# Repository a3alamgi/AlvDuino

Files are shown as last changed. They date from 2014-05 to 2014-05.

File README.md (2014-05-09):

AlvDuino
========	
After breaking an Arduino Uno I decided to build one instead of buying one. Using CadSoft EAGLE I designed a PCB layout for a custom Arduino Uno R3 board which I named the AlvDuino. I read through the Uno schematic to understand the basic hardware and overall design. I removed USB functionality and used a simpler design that can be programmed through an external programmer (USBTinyISP).  

Arduino Uno design and information can be found here: http://arduino.cc/en/Main/ArduinoBoardUno   

Here is an image of the AlvDuino:  
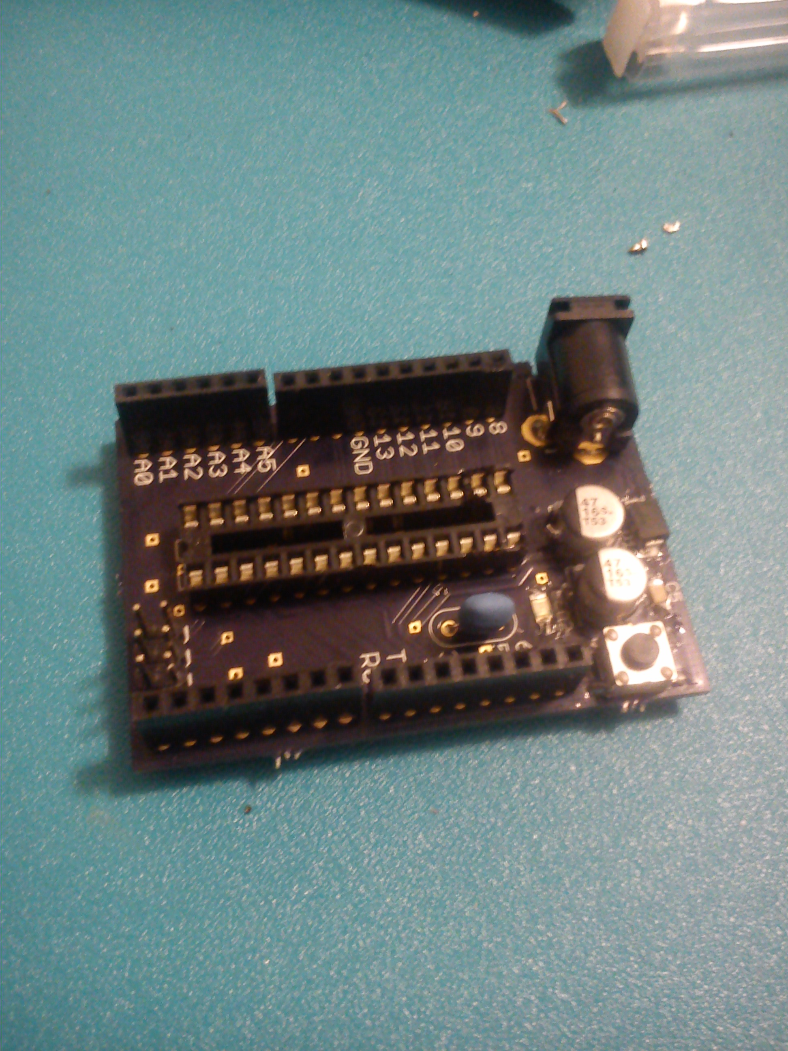
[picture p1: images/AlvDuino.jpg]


Click here to see AlvDuino in use:  
<a href="https://youtu.be/0XYK6YoSBJY">https://youtu.be/0XYK6YoSBJY</a>

Materials:
---------
Researched into use of components in the schematic and selected appropriate packages for soldering and minimizing board space
-	x3, 0.1uF ceramic capacitor, package 1206
-	x2, 47uF aluminum capacitor, SMD
-	x1, 10kΩ resistor, package 1206
-	x2, 1kΩ resistor, package 1206
-	x1, 1MΩ resistor, package 1206
-	x1, green LED, SMD
-	x2, diode, package DO214AA 
-	x1, tactile switch
-	x1, 2x3 vertical pin header 
-	x1, 1x6 female connector header
-	x2, 1x8 female connector header
-	x1, 1x10 female connector header
-	x1, 2.1mm power connector jack
-	x1, 28 position IC socket 
-	x1, 5V regulator, package SOT223, [NCP1117ST50T3G](http://www.onsemi.com/pub_link/Collateral/NCP1117-D.PDF)
-	x1, ceramic 16MHz resonator, radial-3 lead, [CSTL16M0X53-A0](http://search.murata.co.jp/Ceramy/image/img/w_hinm/L0430E.pdf)
-	x1, ATMEGA328-P DIP chip, [ATMEGA328P-PU](http://www.atmel.com/Images/doc8161.pdf)
-	Soldering assembly (solder, iron, braid, etc.)  

Design & Assembly:
-----------------
-	Designed a PCB layout for an Arduino Uno board with Atmega328P to minimize size while retaining functionality (see Figure 1)
-	Rearranged output pin positions for easier board routing
-	Positioned all pins with 0.1” pitch (or a multiple of) so that any prototype board can be used as a custom shield
-	Ordered components from DigiKey/Newark and PCB from OSHPark
-	Soldered and assembled all the components to the board
-	Used ICSP headers used to upload program through an external programmer (USBTinyISP)

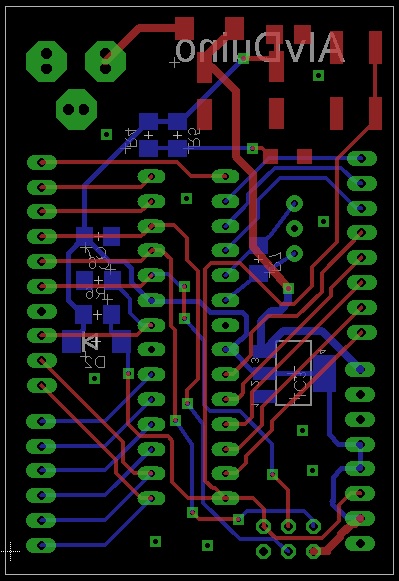
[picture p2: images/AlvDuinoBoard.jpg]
  
Figure 1: AlvDuino PCB layout

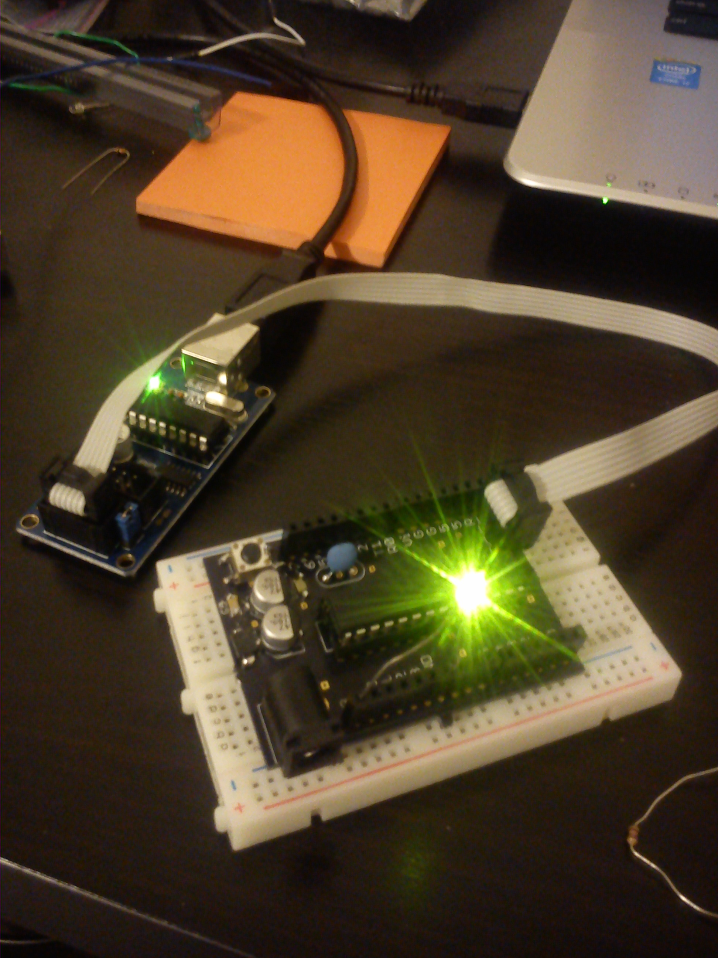
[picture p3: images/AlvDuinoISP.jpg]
  
Figure 2: Completed AlvDuino Board and USBTinyISP

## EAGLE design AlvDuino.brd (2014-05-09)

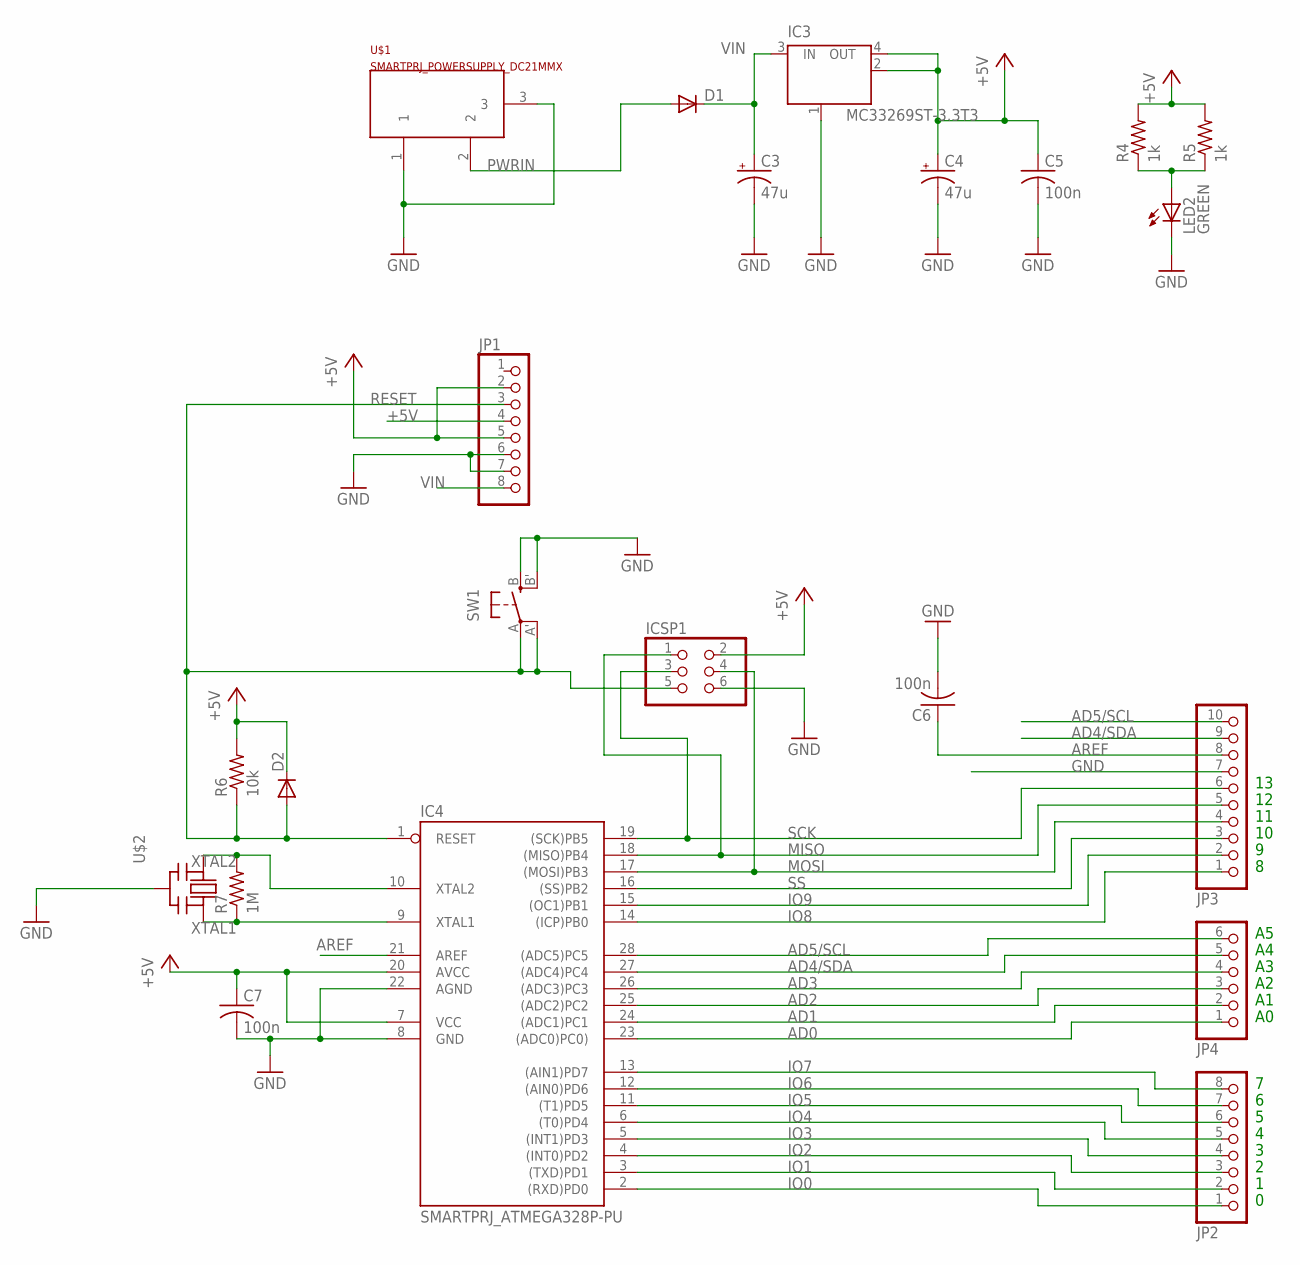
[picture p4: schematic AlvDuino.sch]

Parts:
C3, C4: 47u; PANASONIC_D
C5, C6, C7: 100n; C1206
D1, D2: DIODE-DO214AA; DO214AA
IC3: MC33269ST-3.3T3; SOT223
IC4: SMARTPRJ_ATMEGA328P-PU; SMARTPRJ_DIL28-3
ICSP1: PINHD-2X3; 2X03
JP1, JP2: PINHD-1X8; 1X08
JP3: PINHD-1X10; 1X10
JP4: PINHD-1X6; 1X06
LED2: GREEN; CHIPLED_1206
R4, R5: 1k; R1206
R6: 10k; R1206
R7: 1M; R1206
SW1: SPST_TACT-EVQQ2; EVQ-Q2
U$1: SMARTPRJ_POWERSUPPLY_DC21MMX; SMARTPRJ_POWERSUPPLY_DC-21MM
U$2: CERMOSCILL-THM; CERM_OSC

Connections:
+5V: C4.+, C5.1, C7.1, D2.C, IC3.2 (OUT), IC3.4 (OUT), IC4.7 (VCC), IC4.20 (AVCC), ICSP1.2, JP1.2, JP1.4, JP1.5, R4.2, R5.2, R6.2
AD0: IC4.23 ((ADC0)PC0)), JP4.1
AD1: IC4.24 ((ADC1)PC1), JP4.2
AD2: IC4.25 ((ADC2)PC2), JP4.3
AD3: IC4.26 ((ADC3)PC3), JP4.4
AD4/SDA: IC4.27 ((ADC4)PC4), JP3.9, JP4.5
AD5/SCL: IC4.28 ((ADC5)PC5), JP3.10, JP4.6
AREF: C6.1, IC4.21 (AREF), JP3.8
GND: C3.-, C4.-, C5.2, C6.2, C7.2, IC3.1 (GND/ADJ), IC4.8 (GND), IC4.22 (AGND), ICSP1.6, JP1.6, JP1.7, JP3.7, LED2.C, SW1.B (S), SW1.B' (S1), U$1.1, U$1.3, U$2.P$2 (GND)
IO0: IC4.2 ((RXD)PD0), JP2.1
IO1: IC4.3 ((TXD)PD1), JP2.2
IO2: IC4.4 ((INT0)PD2), JP2.3
IO3: IC4.5 ((INT1)PD3), JP2.4
IO4: IC4.6 ((T0)PD4), JP2.5
IO5: IC4.11 ((T1)PD5), JP2.6
IO6: IC4.12 ((AIN0)PD6), JP2.7
IO7: IC4.13 ((AIN1)PD7), JP2.8
IO8: IC4.14 ((ICP)PB0), JP3.1
IO9: IC4.15 ((OC1)PB1), JP3.2
MISO: IC4.18 ((MISO)PB4), ICSP1.1, JP3.5
MOSI: IC4.17 ((MOSI)PB3), ICSP1.4, JP3.4
unnamed: LED2.A, R4.1, R5.1
PWRIN: D1.A, U$1.2
RESET: D2.A, IC4.1 (RESET), ICSP1.5, JP1.3, R6.1, SW1.A, SW1.A' (P1)
SCK: IC4.19 ((SCK)PB5), ICSP1.3, JP3.6
SS: IC4.16 ((SS)PB2), JP3.3
VIN: C3.+, D1.C, IC3.3 (IN), JP1.8
XTAL1: IC4.9 (XTAL1), R7.1, U$2.P$3 (OUT)
XTAL2: IC4.10 (XTAL2), R7.2, U$2.P$1 (IN)

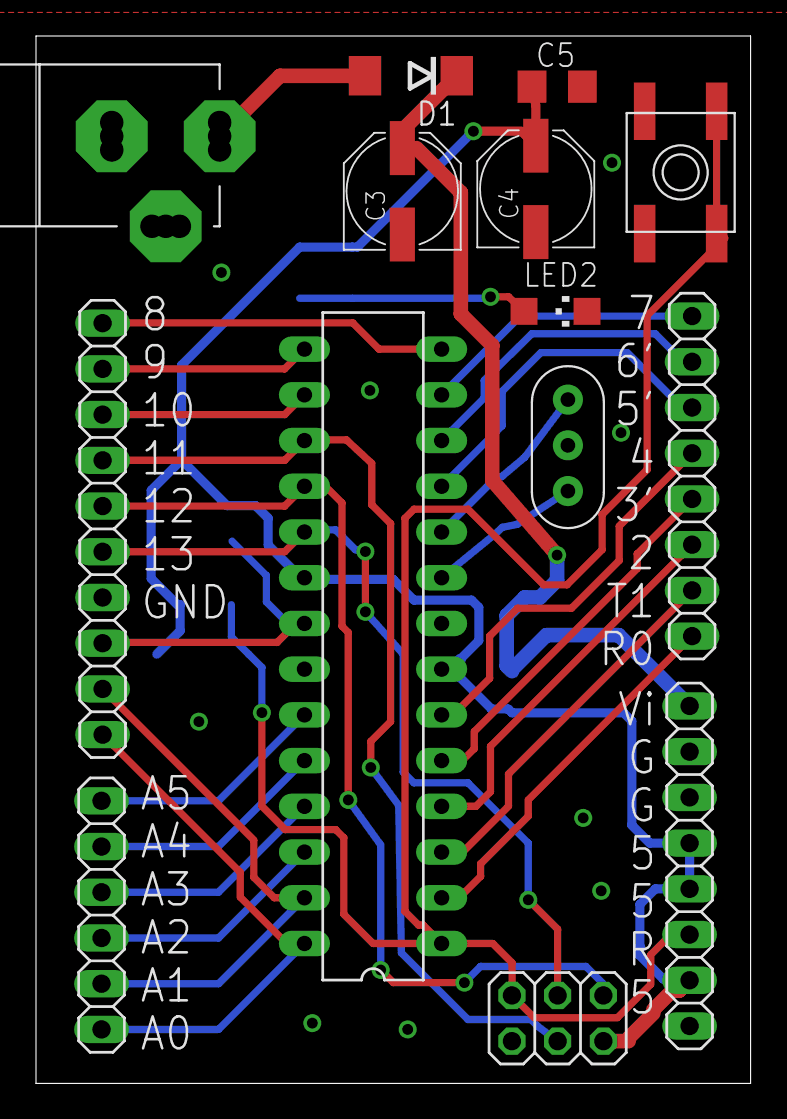
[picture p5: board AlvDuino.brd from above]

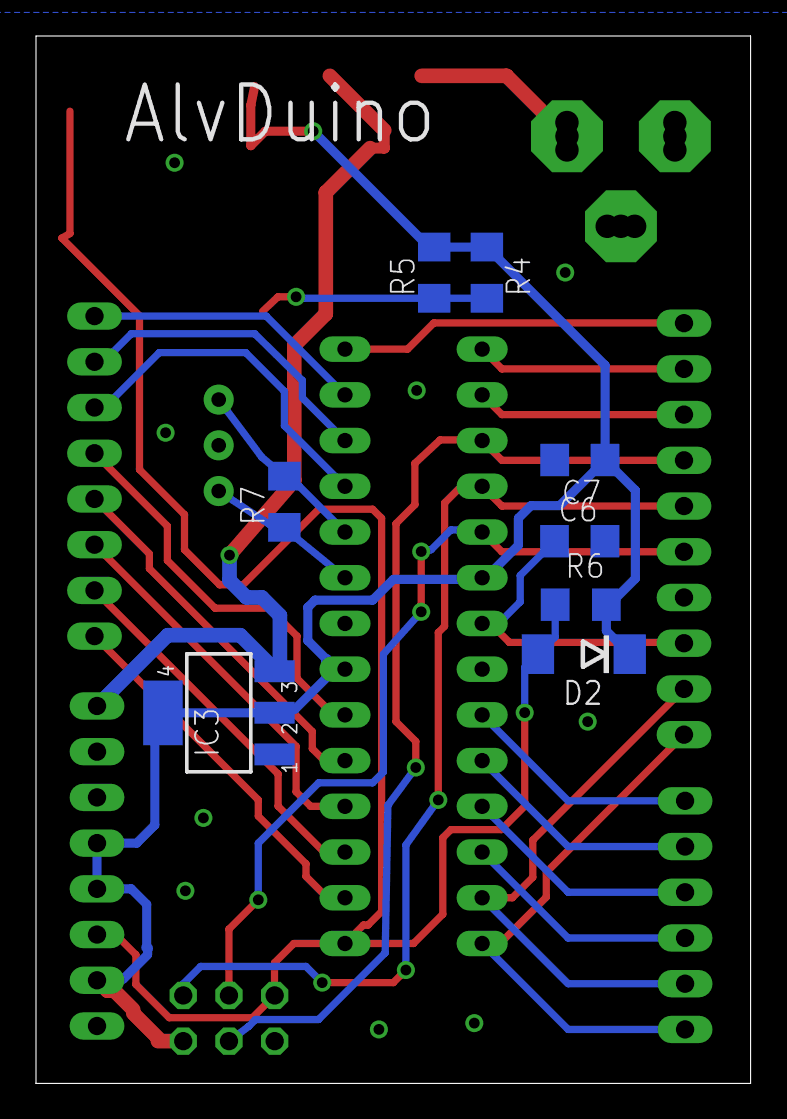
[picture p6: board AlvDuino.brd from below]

Board: 2 copper layers, 39.7 x 58.2 mm, 22 parts (8 on the bottom side), 29 nets.
